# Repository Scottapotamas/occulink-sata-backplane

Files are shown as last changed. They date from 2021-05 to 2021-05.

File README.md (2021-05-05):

# Occulink 4i to 4x SATA Backplane

A quad 2.5in SATA 'backplane' which connects via SFF-8611 (Occulink).

Intended as a one-off to increase packaging density (and neaten wiring) for my SFF flash-storage server.

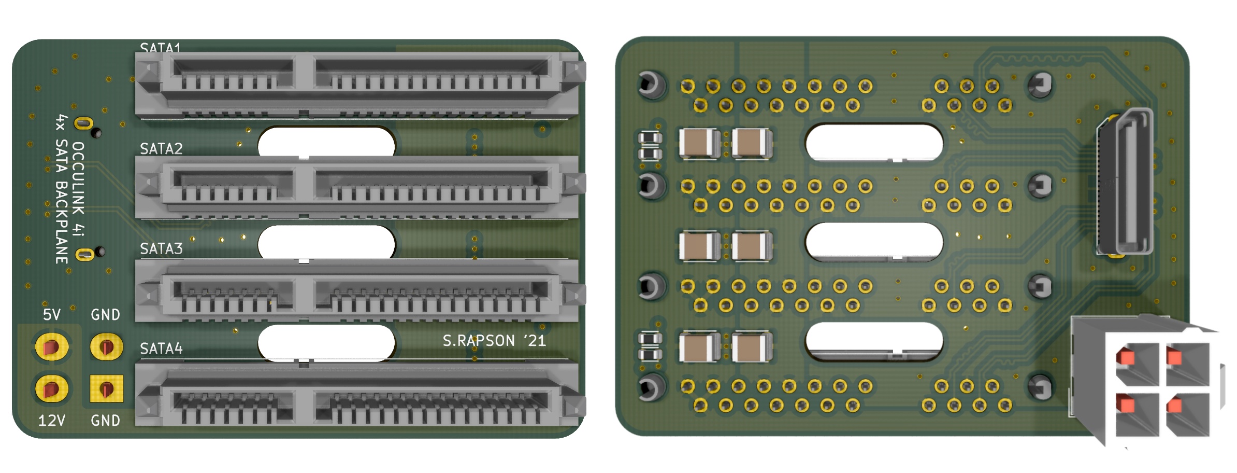
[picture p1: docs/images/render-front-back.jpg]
render-front-back


# Data

This board aims to behave in the same manner as the Occulink CBL-SAST-0933 cable which uses a SFF-8611 connector to break out 4x SATA 7-pin connectors.

On the Asrock Rack X570D4I-2T motherboard I'm using, the OCU1 and OCU2 connectors are connected via the chipset and can operate in PCIe4x4 or 4x SATA mode.

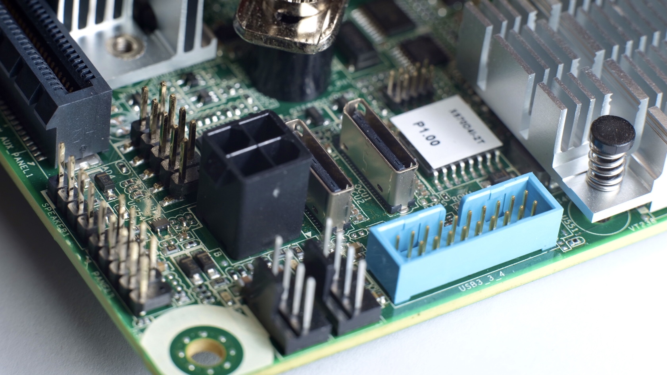
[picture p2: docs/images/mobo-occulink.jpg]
mobo-occulink


# Power

In some situations (mine) the motherboard provides a power connector.

I don't include 3.3V supply to the disks, as most manufacturers don't use it, and some re-use the 3.3V pins for out-of-spec functionality (looking at you WD).

This board matches the pinout with the same Molex MicroFit 4-pin connector. It's also really easy to create a custom loom from a modular powersupply.

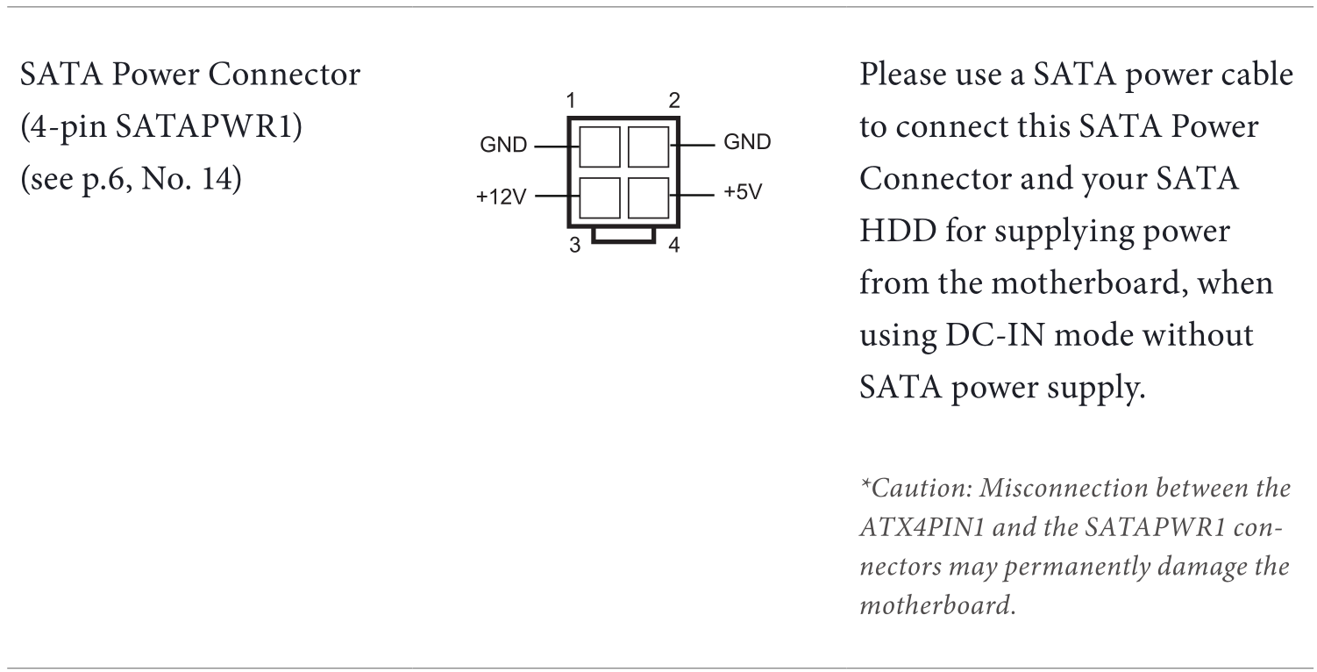
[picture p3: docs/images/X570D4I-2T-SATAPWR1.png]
X570D4I-2T-SATAPWR1


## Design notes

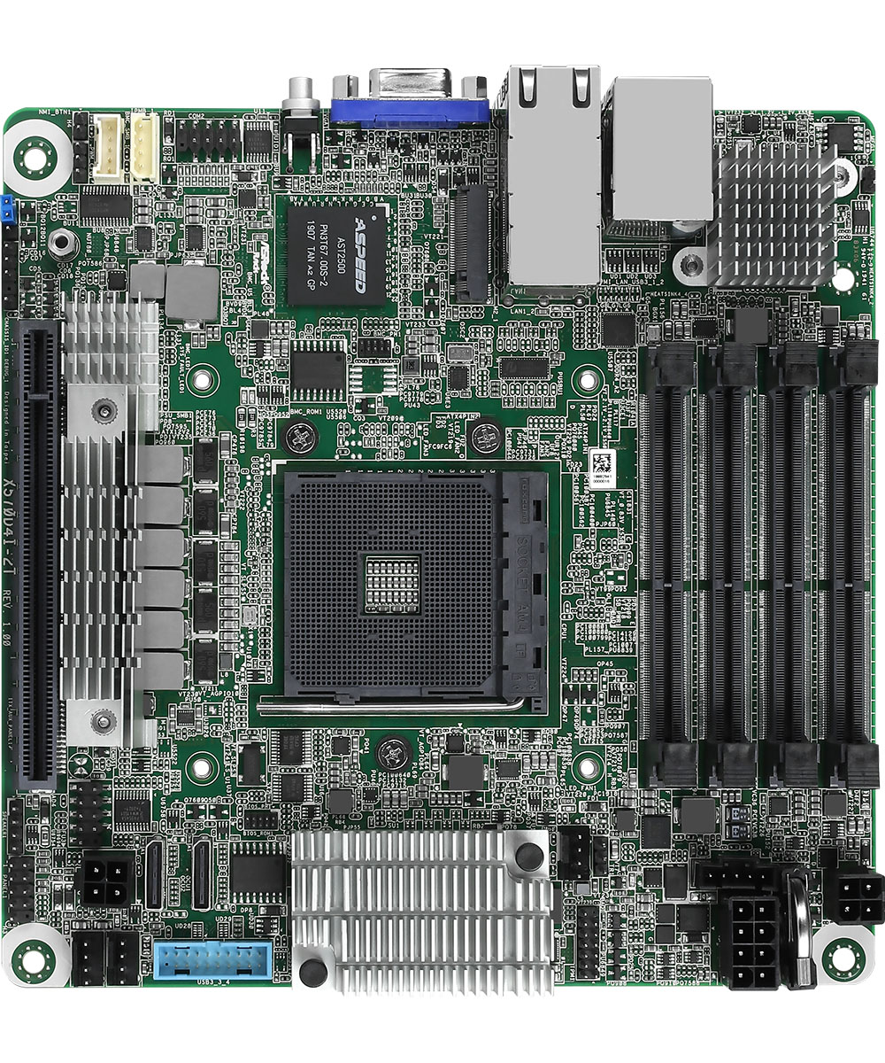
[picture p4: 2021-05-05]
docs/images/X570D4I-2T-motherboard.jpg

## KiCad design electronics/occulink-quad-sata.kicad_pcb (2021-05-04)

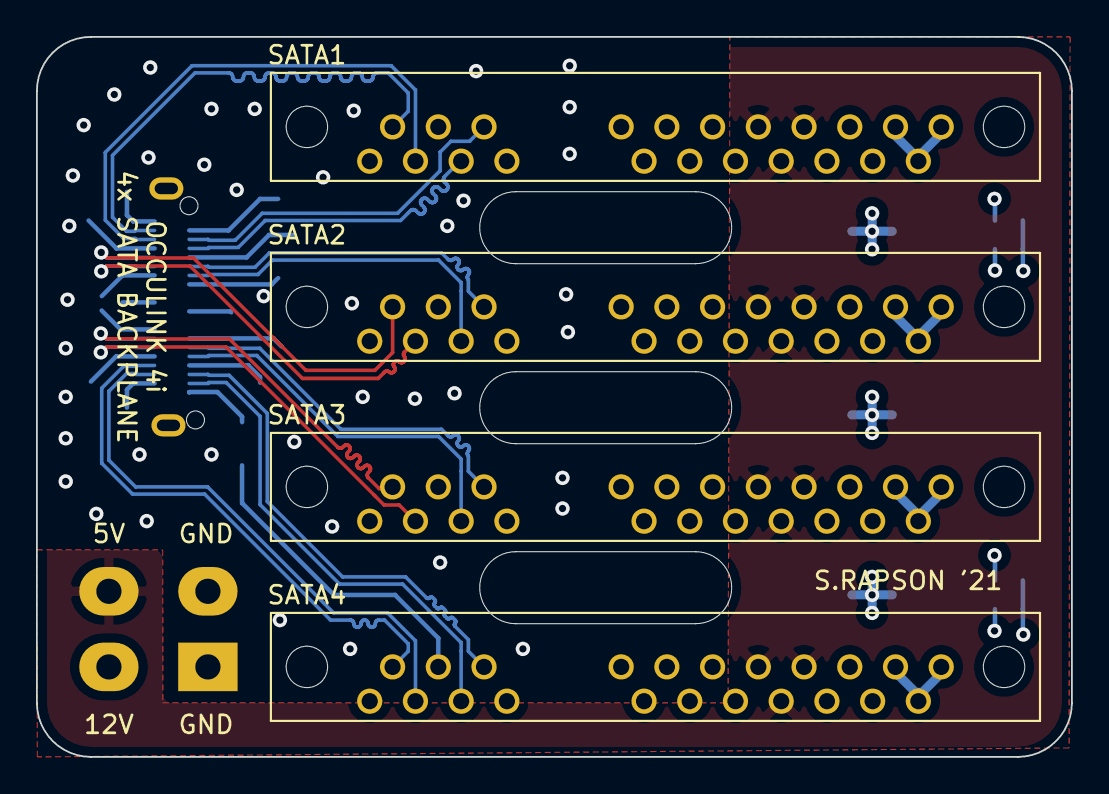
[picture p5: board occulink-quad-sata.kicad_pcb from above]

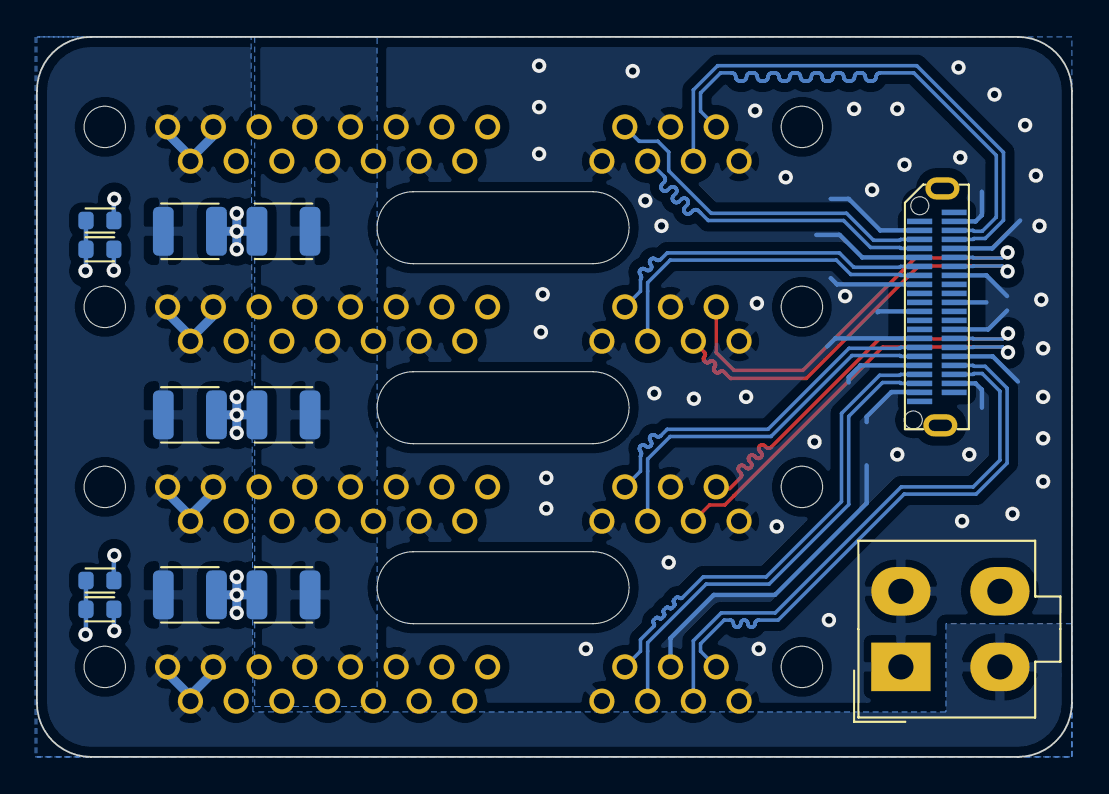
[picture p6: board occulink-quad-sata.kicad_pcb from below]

Board: 4 copper layers, 57.5 x 40.0 mm, 16 parts (12 on the bottom side), 23 nets.

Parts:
C1, C2, C3, C5, C6, C7: 10u_X7S_3225M; CAPC3225X170N
P0: MOLEX_NANOPITCH_42_WAY; MOLEX_NANOPITCH_171983-2342
P1, P2, P3, P4: MOLEX_SATA_COMBO; MOLEX_SATA_877011001
P5: MOLEX_MINIFIT_JR_2x2_WAY; Molex_Mini-Fit_Jr_5566-04A_2x02_P4.20mm_Vertical
R1, R2, R3, R4: 0R_1608M; RESC1608X50N

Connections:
+5V: C5.1, C6.1, C7.1, P1.P7, P1.P8, P1.P9, P2.P7, P2.P8, P2.P9, P3.P7, P3.P8, P3.P9, P4.P7, P4.P8, P4.P9, P5.4
+12V: C1.2, C2.2, C3.2, P1.P13, P1.P14, P1.P15, P2.P13, P2.P14, P2.P15, P3.P13, P3.P14, P3.P15, P4.P13, P4.P14, P4.P15, P5.3
/RX0+: P0.A3, P1.S6
/RX0-: P0.A4, P1.S5
/RX1+: P0.A6, P2.S6
/RX1-: P0.A7, P2.S5
/RX2+: P0.A15, P3.S6
/RX2-: P0.A16, P3.S5
/RX3+: P0.A18, P4.S6
/RX3-: P0.A19, P4.S5
/TX0+: P0.B3, P1.S2
/TX0-: P0.B4, P1.S3
/TX1+: P0.B6, P2.S2
/TX1-: P0.B7, P2.S3
/TX2+: P0.B15, P3.S2
/TX2-: P0.B16, P3.S3
/TX3+: P0.B18, P4.S2
/TX3-: P0.B19, P4.S3
GND: C1.1, C2.1, C3.1, C5.2, C6.2, C7.2, P0.A2, P0.A5, P0.A8, P0.A11, P0.A14, P0.A17, P0.A20, P0.B2, P0.B5, P0.B8, P0.B11, P0.B14, P0.B17, P0.B20, P1.P4, P1.P5, P1.P6, P1.P10, P1.P12, P1.S1, P1.S4, P1.S7, P2.P4, P2.P5, P2.P6, P2.P10, P2.P12, P2.S1, P2.S4, P2.S7, P3.P4, P3.P5, P3.P6, P3.P10, P3.P12, P3.S1, P3.S4, P3.S7, P4.P4, P4.P5, P4.P6, P4.P10, P4.P12, P4.S1, P4.S4, P4.S7, P5.1, P5.2, R1.2, R2.2, R3.2, R4.2
unnamed: P1.P11, R1.1
unnamed: P2.P11, R2.1
unnamed: P3.P11, R3.1
unnamed: P4.P11, R4.1

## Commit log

2021-04-30 Stubbed connectors onto sch/pcb
    Made symbols and footprints
    [occulink-quad-sata.kicad_pcb, occulink-quad-sata.sch]
2021-05-01 Continued schematic
    [occulink-quad-sata.sch]
2021-05-02 PCB layout tests
    [occulink-quad-sata.kicad_pcb]
2021-05-02 Continued routing/layout
    Most pours done
    [occulink-quad-sata.kicad_pcb]
2021-05-03 Diff pair skew tuning
    [occulink-quad-sata.kicad_pcb]
2021-05-04 Minor board tweaks
    [occulink-quad-sata.kicad_pcb]
